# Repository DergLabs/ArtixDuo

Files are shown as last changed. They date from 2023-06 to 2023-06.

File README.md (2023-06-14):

# ArtixDuo
A Dual Artix-7 FPGA board intended for developing Chip-Chip interface busses and advanced FPGA projects

**Overview**

This board is currently on Rev 2. As testing and bringup continue, more changes may be made. Original Altium Files have been provided along with a PDF schematic file. Vivado XDC files will be added. 

Two XDC files are needed, one for FPGA1 and one for FPGA0. They cannot be interchanged!

**SMC Fimrware**

The SMC (System Management Controller) is an RP2040 responsible for monitoring power, voltage rails and currents. It uses an i2C bus communicating with INA260 power monitor IC's present on all major FPGA voltage rails. Whene connected to a serial terminal the SMC will display the realtime voltage, curent and power of each rail. Tera Term works best on windows and Serial on MacOS. Make sure that the serial window is large enough to fit the entire message otherwise it will not print correctly. The SMC is also capable of the following: 
- Generate CLK signals for both FPGA's from (Tested and verified upto 200MHZ)
- Communicate to both FPGA's via SPI. !!! IF YOU DO USE THIS THEN YOU CANNOT USE THE SMC TO GENERATE FPGA CLOCKS !!!
- Display Board Status and othe information on i2C OLED (Coming in Rev 2)
- Enable/Disable each power rail

When the Board is plugged in, you must wait for the SMC to boot and flash its onboard LED 3 times. Once that is complete you can enable the main power supply by pressing the SMC user button. The onboard LED by the SMC will light up when the DC-DC is active.
The SMC firmware is in beta and more updates are to come.

**Onboard MCU**

The onboard MCU is also an RP2040. The MCU is connected to each FPGA with a 9-bit bus (1-bit for clk, 8-bits for data), and can be programmed to perform any functions the user would like. No firmware is provided for this chip as it's function is user specific.

**FT4232**

The FT4232 is a combination USB-JTAG and UART bridge. Two independent JTAG and UART busses go to each FPGA. Onboard MUX's are used to select between the FT4232 and the JTAG headders. Currently Vivado does not support using two independent JTAG busses on a single FT4232 :(, Only one FPGA can be used at a time and the other must be connected via the JTAG header. There are two onboard headers for selecting between the JTAG header and FT4232. When in the "1" position, the FT4232 is selected. When in the "0" position, the JTAG header is selected. 

**FPGA0 IO**

FPGA0 has acess to the following IO:
- 48 User IO pins available on the 0.1" headers. These IO pins pass through bi-directional 100Mb/s Buffers and should be able to reliably operate upto 50Mhz and potentialy beyond.
- 4x PMOD headers (32 IO total). These IO's also pass through bi-directional buffers.
- 4x 6.6Gb/s GTP Transceivers. These have been routed with 100 Ohm differential pairs  
- 1 XADC Input
- 100-bit Bus to FPGA1
- 9-bit Bus to MCU
- SPI Bus to SMC
- 4 User buttons
- 8 user LED's
- 512Mb Octal SPI PSRAM operating at upto 200Mhz. This is a DDR memory capable of upto 400MB/s (3.2Gb/s)

**FPGA1 IO**

FPGA1 has acess to the following IO:
- 48 User IO pins available on the 0.1" headers. These IO pins pass through bi-directional 100Mb/s Buffers and should be able to reliably operate upto 50Mhz and potentialy beyond.
- 4x PMOD headers (32 IO total). These IO's also pass through bi-directional buffers.
- Displayport RX and TX via 6.6Gb/s GTP Transceivers. These have been routed with 100 ohm differential pairs   
- 1 XADC Input
- 100-bit Bus to FPGA1
- 9-bit Bus to MCU
- SPI Bus to SMC
- 4 User buttons
- 8 user LED's

**Power**

A LTCC3370 is used to provide the 4 power rails for each FPGA (3.3V, 1.8V, 1.2V and 1.0V). Each rail is capable of supplying up to 2A. In the event that more power is needed, an addon board will be required to provide suplemental power. With the current Artix-7 35T chips, this should not be needed, however these chips are pin compatible with specific 50T and 75T parts. If these parts were to be used, suplemental power may be needed. 
The DC-DC converter is configured to operate at 2Mhz Burst Mode.

**Top View**

ArtixDuo Top (Rev2)

**Bottom View** 

ArtixDuo Bottom (Rev2)

**Assembled Rev1 Board**

Assembled Board (Rev1)

**TODO For Rev 2:**

- Add Via Stitching to High speed serial traces at layer transitions
- Add delay matching to Chip-chip bus
- Add delay matching to FPGA-MCU busses

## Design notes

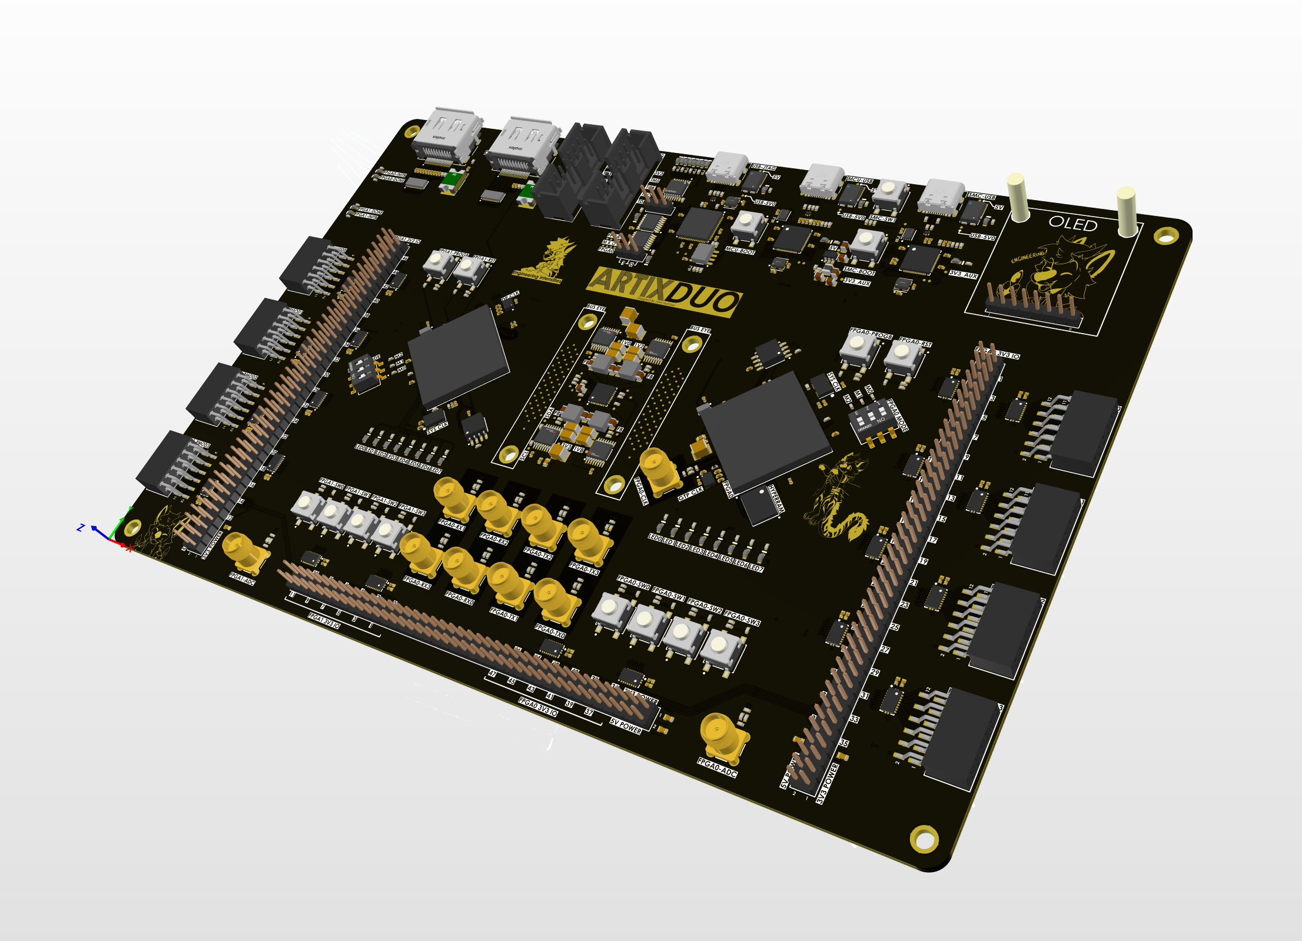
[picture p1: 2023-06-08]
top.png

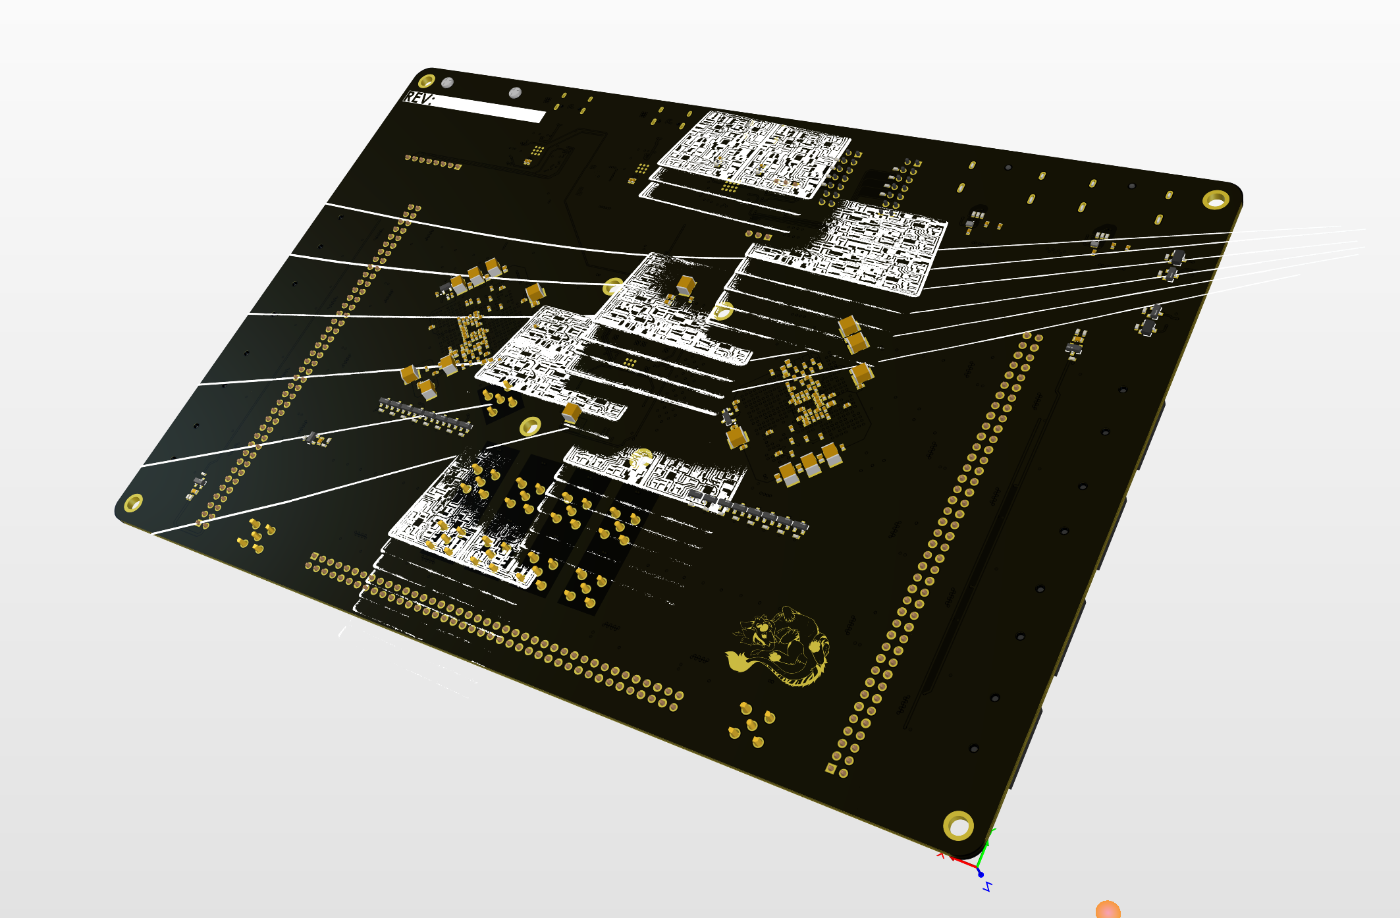
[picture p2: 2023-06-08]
bot.png

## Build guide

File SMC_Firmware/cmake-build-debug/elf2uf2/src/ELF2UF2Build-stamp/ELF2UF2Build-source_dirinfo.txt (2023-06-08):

# This is a generated file and its contents are an internal implementation detail.
# The download step will be re-executed if anything in this file changes.
# No other meaning or use of this file is supported.

method=source_dir
command=
source_dir=/Users/john/Desktop/RP2040/pico-sdk/tools/elf2uf2
work_dir=

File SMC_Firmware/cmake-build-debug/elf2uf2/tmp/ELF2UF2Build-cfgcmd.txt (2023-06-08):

cmd='/Applications/CLion.app/Contents/bin/cmake/mac/bin/cmake;-DCMAKE_MAKE_PROGRAM:FILEPATH=/Applications/CLion.app/Contents/bin/ninja/mac/ninja;-GNinja;<SOURCE_DIR><SOURCE_SUBDIR>'

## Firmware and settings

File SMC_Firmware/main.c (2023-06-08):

#include <stdio.h>
#include "pico/stdlib.h"
#include "hardware/i2c.h"
#include "hardware/irq.h"
#include "hardware/pwm.h"


#define MCU_CLK 200 //Set clock to 200Mhz
#define I2C_BAUDRATE 2000 //Set in terms of Kb/s
#define FPGA0_CLK_CYCLE 1 //Set the PWM cycle speed to 2 cycles. Frequency = MCU CLK / Cycle + 1  --> 200/2 = 100Mhz
#define FPGA1_CLK_CYCLE 1
#define REV "1.5b" //Firmware Revision. Update when changed

//USER IO Definitions
const uint LED_PIN = 25; //GPIO 25
const uint BUTTON_PIN = 20; //GPIO 20
const uint FPGA0_SPI_CLK = 18; //FPGA SPI CLK can be used as system clock as well. Must choose between SPI and SYS_CLK function!!!
const uint FPGA1_SPI_CLK = 14;

//PMU CTRL Definitions
const uint PMU_MODE = 6; 
const uint PMU_EN_CH1 = 8; 
const uint PMU_EN_CH2 = 10;
const uint PMU_EN_CH3 = 9;
const uint PMU_EN_CH4 = 7; 
const uint PMU_PGOOD = 14;
const uint PMU_TEMP = 26;

//PWR MON Definitions
const uint PWR_MON_ADDR[4] = {0x40, 0x41, 0x42, 0x43};

void initIO(){
        /*TODO: Add defines for Display module and FPGA IO Pins

    */

    sleep_ms(250);
    printf("Initialzing IO...\n");
    sleep_ms(250);

    gpio_init(LED_PIN);
    gpio_set_dir(LED_PIN, GPIO_OUT);
    gpio_init(BUTTON_PIN);
    gpio_set_dir(BUTTON_PIN, GPIO_IN);
    gpio_pull_up(BUTTON_PIN);

    gpio_init(PMU_MODE);
    gpio_set_dir(PMU_MODE, GPIO_OUT);
    gpio_init(PMU_EN_CH1);
    gpio_set_dir(PMU_EN_CH1, GPIO_OUT);
    gpio_init(PMU_EN_CH2);
    gpio_set_dir(PMU_EN_CH2, GPIO_OUT);
    gpio_init(PMU_EN_CH3);
    gpio_set_dir(PMU_EN_CH3, GPIO_OUT);
    gpio_init(PMU_EN_CH4);
    gpio_set_dir(PMU_EN_CH4, GPIO_OUT);
    gpio_init(PMU_PGOOD);
    gpio_set_dir(PMU_PGOOD, GPIO_IN);


    gpio_set_function(FPGA0_SPI_CLK, GPIO_FUNC_PWM);
    uint slice_num_0 = pwm_gpio_to_slice_num(FPGA0_SPI_CLK);
    // Set period
    pwm_set_wrap(slice_num_0, FPGA0_CLK_CYCLE);
    // Set channel A output for 50% duty cycle
    pwm_set_chan_level(slice_num_0, PWM_CHAN_A, ((FPGA0_CLK_CYCLE+1)/2));
    // Set the PWM running
    pwm_set_enabled(slice_num_0, true);

    gpio_set_function(FPGA1_SPI_CLK, GPIO_FUNC_PWM);
    uint slice_num_1 = pwm_gpio_to_slice_num(FPGA1_SPI_CLK);
    // Set period
    pwm_set_wrap(slice_num_1, FPGA1_CLK_CYCLE);
    // Set channel A output for 50% duty cycle
    pwm_set_chan_level(slice_num_1, PWM_CHAN_A, ((FPGA1_CLK_CYCLE+1)/2));
    // Set the PWM running
    pwm_set_enabled(slice_num_1, true);

    return; 
}

void blinkStatusLED(){
    for(int i = 0; i < 3; i++){
        gpio_put(LED_PIN, 1);
        sleep_ms(150);
        gpio_put(LED_PIN, 0);
        sleep_ms(150);
    }
    return;
}

void initI2C(){
    uint8_t regbuf[2];
    uint8_t MFRID_PTR = 0xFE;
    uint8_t CFG_REG = 0x00;
    uint8_t CFG_DATA[3] = {0x00, 0xFF, 0xFF}; // Based on datasheet, send CFG ponter address first, then the two bytes of data

    i2c_init(i2c_default, I2C_BAUDRATE * 1000); // Using default I2C pins 4 and 5. Testing with 250Kb/s Bus speed, will increase later
    printf("Setting I2C to Default, %dKb/s\n", I2C_BAUDRATE);
    sleep_ms(150);
    gpio_set_function(PICO_DEFAULT_I2C_SDA_PIN, GPIO_FUNC_I2C);
    gpio_set_function(PICO_DEFAULT_I2C_SCL_PIN, GPIO_FUNC_I2C);
    printf("I2C initialzied as default. Reading INA260 MFR ID...\n");

    for(int i=0; i<(sizeof(PWR_MON_ADDR)/sizeof(PWR_MON_ADDR[0])); i++){
        i2c_write_blocking(i2c_default, PWR_MON_ADDR[i], &MFRID_PTR, 1, true); //Need to first address the register
        i2c_read_blocking(i2c_default, PWR_MON_ADDR[i], regbuf, 2, true); //Then read the data from register
        if (regbuf[0] == 0 && regbuf[1] == 0){
            printf("Error: Invalid response from Power monitor 0x%x. Please check chip and bus functionality.\n", PWR_MON_ADDR[i]);
            break;
        }
        else
        {
            printf("PWR MON 0x%x (CH%d) OK - MFR ID: 0x%x%x\n", PWR_MON_ADDR[i], i, regbuf[0], regbuf[1]);
            sleep_ms(250);
        }
    }

    printf("Configuring Power Monitor Registers...\n");
    for(int i=0; i<(sizeof(PWR_MON_ADDR)/sizeof(PWR_MON_ADDR[0])); i++){
        i2c_write_blocking(i2c_default, PWR_MON_ADDR[i], CFG_DATA, 3, true);
        i2c_read_blocking(i2c_default, PWR_MON_ADDR[i], regbuf, 2, true);

        if (regbuf[0] != CFG_DATA[0] || regbuf[1] != CFG_DATA[1]){
            printf("CH%d register data is: 0x%x%x\n", i, regbuf[0], regbuf[1]);
            printf("Warning: Power Monitor Configuration failed. Default Configuration Used.\n");
        }
        else
        {
            printf("CH%d configured.\n", i);
        }
        sleep_ms(250);
    }

    return;

}

void sysInit(){
    sleep_ms(250);
    printf("Initializing system...\n");
    sleep_ms(250);
    printf("Establishing I2C connection to Power Monitors...\n");
    sleep_ms(250);
    initI2C();
    blinkStatusLED();
}

void readPwrMon(float *voltage, float *current, float *power){
    uint8_t regbuf[2]; //Two Byte buffer to hold 16-bit Voltage/Current/Power readings from Power monitor
    const uint8_t CURRENT_REG = 0x01;
    const uint8_t VOLTAGE_REG = 0x02;
    const uint8_t POWER_REG = 0x03;

    const float VOLTAGE_SCALE = 0.00125;
    const float CURRENT_SCALE = 0.00125;
    const float POWER_SCALE = 0.01;

    uint16_t tempVoltage;
    uint16_t tempCurrentUnsigned;
    int16_t tempCurrentSigned;
    uint16_t tempPower;


    for(int i=0; i<(sizeof(PWR_MON_ADDR)/sizeof(PWR_MON_ADDR[0])); i++){
        i2c_write_blocking(i2c_default, PWR_MON_ADDR[i], &VOLTAGE_REG, 1, true);
        i2c_read_blocking(i2c_default, PWR_MON_ADDR[i], regbuf, 2, true);
        tempVoltage = (regbuf[0]<<8) | regbuf[1];
        voltage[i] = (float)((unsigned int)(tempVoltage)*VOLTAGE_SCALE);

        regbuf[0] = 0;
        regbuf[1] = 0;

        i2c_write_blocking(i2c_default, PWR_MON_ADDR[i], &CURRENT_REG, 1, true);
        i2c_read_blocking(i2c_default, PWR_MON_ADDR[i], regbuf, 2, true);
        tempCurrentUnsigned = ((regbuf[0]<<8)) | regbuf[1];
        tempCurrentSigned = (int16_t)tempCurrentUnsigned;
        if(tempCurrentSigned < 0){
            tempCurrentSigned = ~tempCurrentSigned + 1;
        }

        current[i] = (float)(tempCurrentSigned*CURRENT_SCALE);

        regbuf[0] = 0;
        regbuf[1] = 0;

        i2c_write_blocking(i2c_default, PWR_MON_ADDR[i], &POWER_REG, 1, true);
        i2c_read_blocking(i2c_default, PWR_MON_ADDR[i], regbuf, 2, true);
        tempPower = (regbuf[0]<<8) | regbuf[1];
        power[i] = (float)(tempPower*POWER_SCALE);

        regbuf[0] = 0;
        regbuf[1] = 0;
    }

    printf("\rVCCIO %0.3fV, %0.3fA, %0.3fW | VCCAUX %0.3fV, %0.3fA, %0.3fW | VCCMGT %0.3fV, %0.3fA, %0.3fW | VCORE %0.3fV, %0.3fA, %0.3fW",
           voltage[0], current[0], power[0], voltage[1], current[1], power[1], voltage[2], current[2], power[2], voltage[3], current[3], power[3]);
    fflush(stdout);
}

int main() {
    
    set_sys_clock_khz((MCU_CLK*1000), true); //Increase clock from 133Mhz to 220Mhz
    stdio_init_all(); 
    sleep_ms(1500);
    printf("\n");
    printf("SMC Firmware Rev: %s\n", REV);
    sleep_ms(250);
    printf("SMC CLK is: %dMhz\n", MCU_CLK);
    sleep_ms(250);
    printf("FPGA0 CLK is: %dMhz\n", (MCU_CLK/(FPGA0_CLK_CYCLE+1)));
    sleep_ms(250);
    printf("FPGA1 CLK is: %dMhz\n", (MCU_CLK/(FPGA1_CLK_CYCLE+1)));
    initIO();
    sleep_ms(250);
    printf("IO Initialization done!\n");
    sysInit();
    sleep_ms(250);
    printf("System Initialization done!\n");

    float current[4] = {0, 0, 0, 0};
    float voltage[4] = {0, 0, 0, 0};
    float power[4] = {0, 0, 0, 0};

    bool pressed;
    bool oldState;
    bool newState;

    while (true) {

        newState = gpio_get(BUTTON_PIN);
        if (oldState == 1 && newState == 0){
            if(pressed==0){
                //printf("Button Pressed\n");
                pressed = 1; 
                gpio_put(PMU_EN_CH1, 1);
                gpio_put(PMU_EN_CH2, 1);
                gpio_put(PMU_EN_CH3, 1);
                gpio_put(PMU_EN_CH4, 1);
                gpio_put(LED_PIN, 1);
            }
            else
            {
                gpio_put(LED_PIN, 0);
                gpio_put(PMU_EN_CH1, 0);
                gpio_put(PMU_EN_CH2, 0);
                gpio_put(PMU_EN_CH3, 0);
                gpio_put(PMU_EN_CH4, 0);
                pressed = 0;
            }
        }
        oldState = newState;
        readPwrMon(voltage, current, power);
        sleep_ms(100);
    }
}

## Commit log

2023-06-08 Added files
    Initial Commit
    [Architecture.SchDoc, ArtixDuo.PrjPcb, Aux PSU.SchDoc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]
2023-06-08 Add Datasheets
    [7_Series_Schematic_Review_Recommendations.xlsm]
2023-06-14 updated files
    [Architecture.SchDoc, ArtixDuo.PrjPcb, FPGA_0.SchDoc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]
